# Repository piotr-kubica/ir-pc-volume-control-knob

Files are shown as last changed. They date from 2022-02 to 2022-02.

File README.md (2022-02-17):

# ir-pc-volume-control-knob
IR and PC volume control knob allows to control 
- prev/next/play/volume on your PC
- tuner/audio-in/on/off/volume of the Denon RCD-M39 amplituner using IR

The goal of this project was to create a volume control knob for multiple devices.

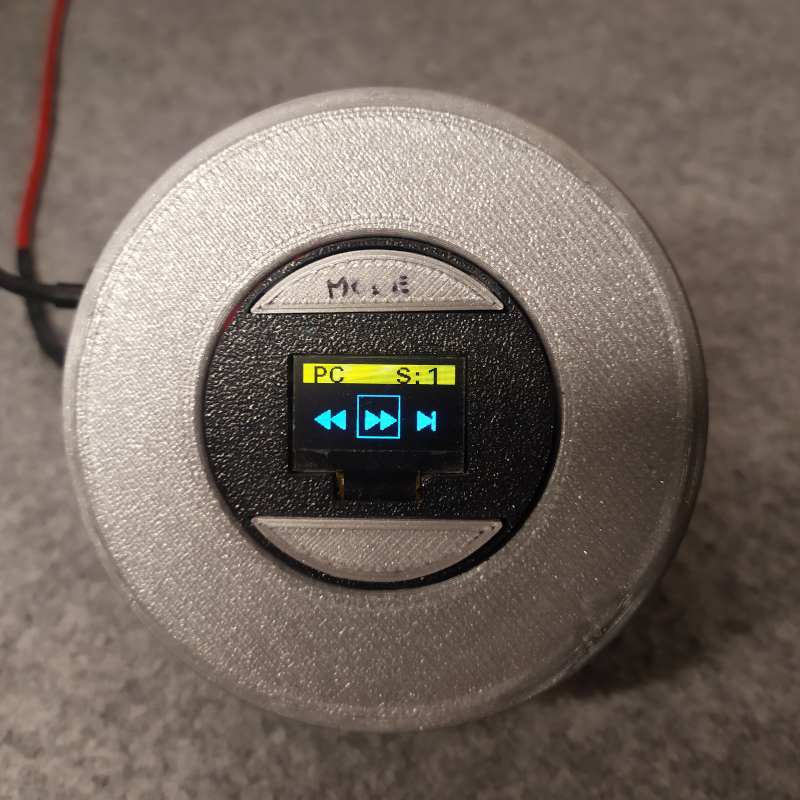
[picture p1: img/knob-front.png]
[](/img/knob-front.png)

## Hardaware
- SparkFun Pro Micro 5v/16Mhz 
- rotary encoder
- ssd1306 oled display (i2c version)
- IR led, transistor and resistor (used in the IR transmitter)
- 3D printed case (see stl and 3mf files)
- M3 bolts, 2x tactile buttons, JST connector and socket, wires, proto board, USB cable, rubber pad (so the knob does not slip on flat surface)

## Software 

I have used Arduino Studio to upload ir-pc-volume-control-knob.ino to the MCU.
I have also created a custom font using the png2bdf cli tool.

## How the control know works
Volume increase/decrease by turning the knob left/right.

Mute by clicking the mute button (it will mute the device with active mode).

Mode is changed by clicking the mode button.

Press once in clickable area to enter selection for mode.
Navigate by turning knob. Press angain to select.

Double click clickable area to change volume stepping ("S:1" or "S:2") for move volume per knob turn.

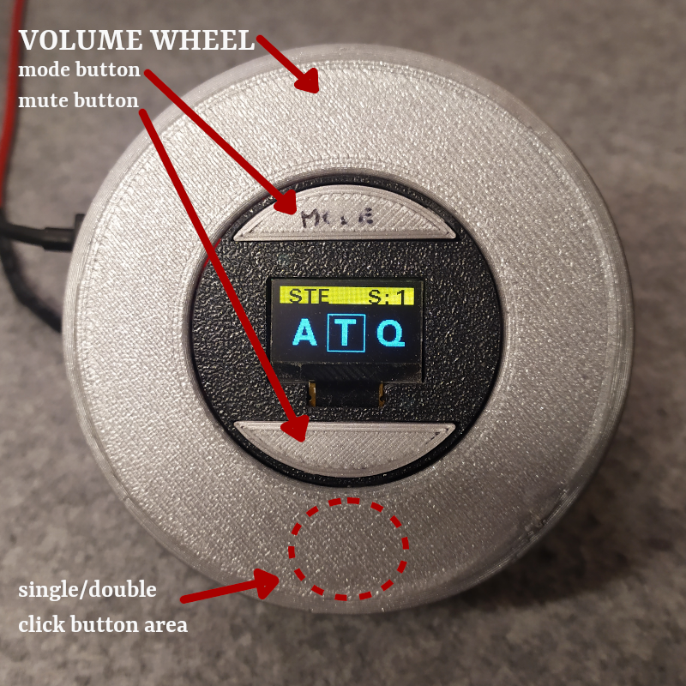
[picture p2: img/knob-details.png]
[](/img/knob-details.png)

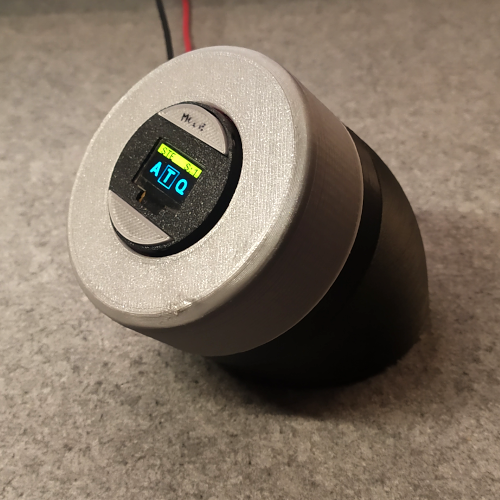
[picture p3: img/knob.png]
[](/img/knob.png )
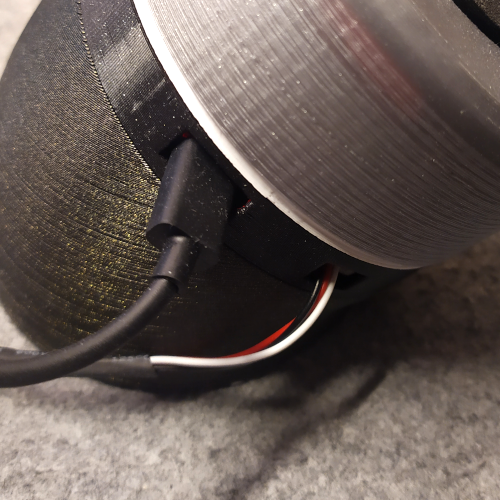
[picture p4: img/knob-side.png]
[](/img/knob-side.png)
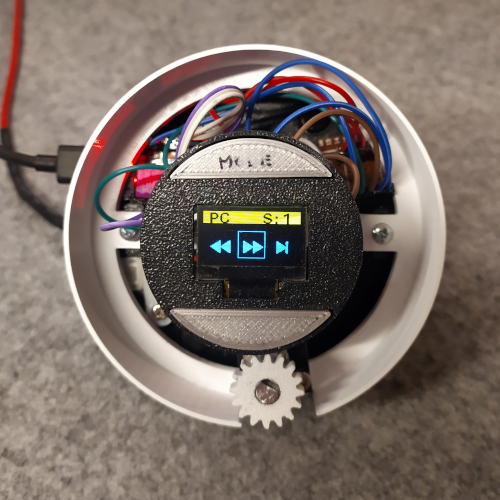
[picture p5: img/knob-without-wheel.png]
[](/img/knob-without-wheel.png)
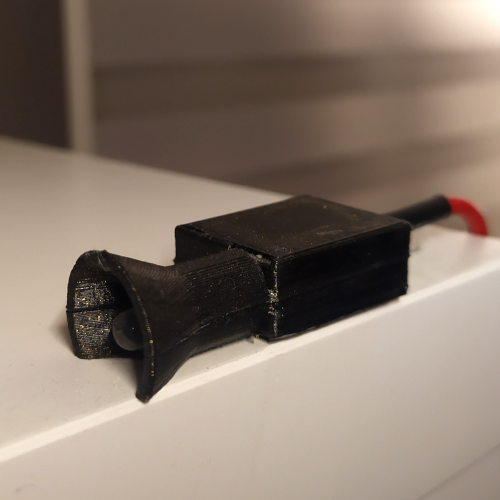
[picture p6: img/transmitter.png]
[](/img/transmitter.png)
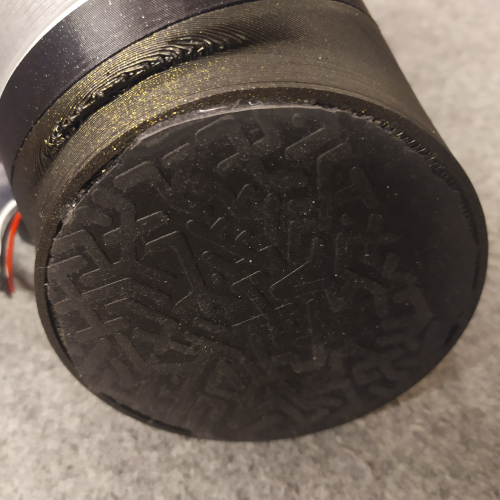
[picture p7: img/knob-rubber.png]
[](/img/knob-rubber.png)

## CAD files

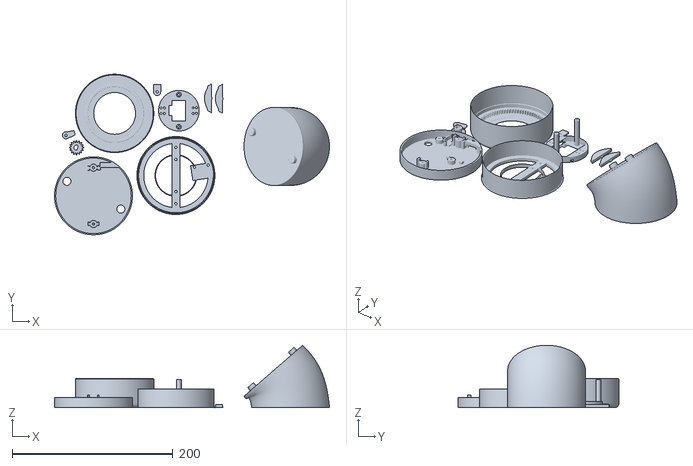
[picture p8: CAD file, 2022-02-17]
stl_3mf/ir-pc-remote-vol-knob.stl
342.1 x 199.8 x 77.6

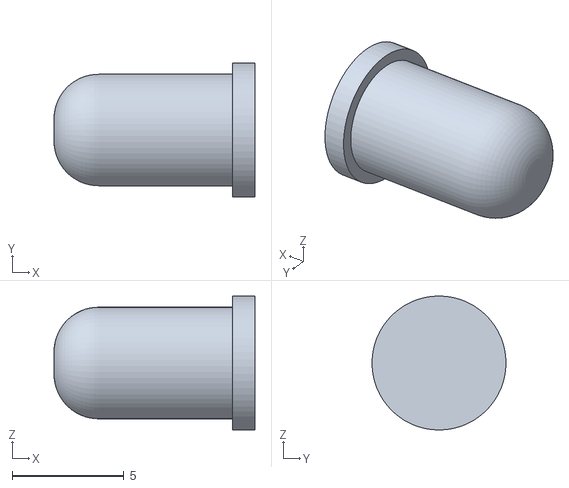
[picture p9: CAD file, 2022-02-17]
stl_3mf/ir-pilot-led.stl
9.00 x 5.99 x 6.00

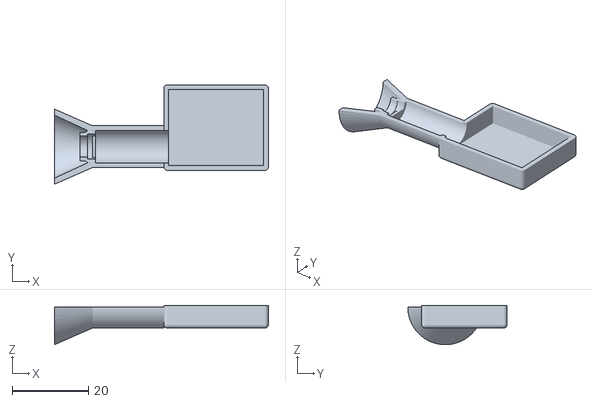
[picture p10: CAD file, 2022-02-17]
stl_3mf/ir-pilot-case.stl
56.2 x 26.1 x 10.3

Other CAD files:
stl_3mf/ir-pc-control-knob-final.3mf

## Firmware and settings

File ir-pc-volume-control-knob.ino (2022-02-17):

/* ProMicro PIN <-> WIRE COLOR MAPPING

3 white oled SCK
2 violet oled SDA

7 btn bonze
8 btn green

A2 violet enc CLK
A1 gray enc DT
A0 white enc SW

*/
#include <Arduino.h>
#include <U8g2lib.h>
#include <SPI.h>
#include <Wire.h>

#include <ClickEncoder.h>
#include <TimerOne.h>
#include <HID-Project.h>
#include <ClickButton.h>
#include <IRremote.h>

#define ENCODER_CLK A0
#define ENCODER_DT A1
#define ENCODER_SW A2
#undef  ENC_DOUBLECLICKTIME
#define ENC_DOUBLECLICKTIME  1500
#undef  ENC_HOLDTIME
#define ENC_HOLDTIME 2000 
#define STEPS_PER_NOTCH 4
ClickEncoder *rotEnc;
int16_t rotLast = 0;
int16_t rotValue = 0;
#define INVERT_KNOB_DIR 1

#define BTN_MODE 7
#define BTN_MUTE 8
ClickButton btn_mode(BTN_MODE, LOW);
ClickButton btn_mute(BTN_MUTE, LOW);

#define MODE_STEREO 0
#define MODE_PC 1
uint8_t mode = MODE_STEREO;
uint8_t mode_offset = 0;
uint8_t volume_step = 1;
String pc_header = String("PC       S: ");
String ste_header = String("STE      S: ");

IRsend irsend;
#define IR_KHZ 38
// no need to #define IR_SEND_PIN 5
// since it's default

#define OLED1306_SCK 3
#define OLED1306_SDA 2
U8G2_SSD1306_128X64_NONAME_1_SW_I2C u8g2(U8G2_R0, OLED1306_SCK, OLED1306_SDA);

#define FIELDS 3
#if INVERT_KNOB_DIR
    #define FIELD_DIFF_NEXT FIELDS-1
    #define FIELD_DIFF_PREV 1
#else
    #define FIELD_DIFF_NEXT 1
    #define FIELD_DIFF_PREV FIELDS-1
#endif

int selected = 1;
int active_choice = false;
unsigned long millis_since_choice = 0;
unsigned long active_choice_timeout_ms = 2000;

// mycust font
#include "mycust_font.h"
// Font list: https://github.com/olikraus/u8g2/wiki/fntlistall
//  https://github.com/olikraus/u8g2/wiki/fntgrpiconic
const int GLYPHS[][3] = { 
    // PC
    { 8, 58, 'C'},  // prev
    {48, 58, 'A'}, // next
    {88, 58, 'B'}, // play/pause
    // STEREO
    {12, 54, 'A'}, // audio in
    {52, 54, 'T'}, // tuner
    {92, 54, 'Q'}, // on / off
};
const int BOX_POS[][4] = { 
    {6, 24, 36, 36},
    {46, 24, 36, 36},
    {86, 24, 36, 36},
};

// size of each array is 99
#define IR_CODE_SIZE 99
const uint16_t IR_AU_IN[]  PROGMEM = {3300,1700, 350,500, 350,450, 350,1350, 350,450, 350,1350, 350,450, 350,1300, 350,500, 350,500, 350,1300, 350,500, 350,450, 350,1300, 350,1350, 350,450, 350,500, 350,500, 350,450, 350,500, 350,450, 350,1350, 350,450, 350,1350, 350,450, 350,500, 350,1300, 350,500, 350,450, 350,500, 350,500, 350,450, 350,1300, 350,500, 350,500, 350,450, 350,500, 350,500, 350,450, 350,1300, 350,500, 350,500, 350,1300, 350,500, 350,450, 350,1300, 350,500, 350,500, 350,1300, 350};
const uint16_t IR_TUNER[]  PROGMEM = {3300,1700, 350,450, 400,450, 350,1300, 350,500, 350,1300, 400,450, 350,1300, 350,450, 400,450, 400,1250, 350,500, 400,450, 350,1300, 350,1300, 400,450, 350,450, 400,450, 400,450, 350,450, 400,450, 350,1300, 400,450, 350,1300, 350,500, 350,450, 400,1250, 400,1300, 350,450, 400,1300, 350,1300, 350,1300, 400,450, 350,450, 400,450, 400,450, 350,450, 400,450, 350,450, 400,1300, 350,450, 400,450, 350,1300, 400,1250, 400,450, 400,450, 350,1300, 350,1300, 400,450, 350};
const uint16_t IR_PWR[]    PROGMEM = {3250,1750, 300,500, 350,500, 300,1350, 350,500, 300,1350, 350,500, 300,1350, 300,550, 300,550, 300,1350, 300,550, 250,550, 300,1400, 250,1350, 350,500, 300,500, 350,550, 250,550, 300,500, 350,550, 250,1350, 350,500, 300,1350, 300,550, 300,1350, 300,550, 300,500, 350,500, 300,1350, 300,1350, 350,500, 300,550, 300,500, 350,500, 300,500, 350,500, 300,550, 300,500, 350,1350, 300,500, 300,1350, 350,500, 300,550, 300,500, 350,500, 300,1350, 300,550, 350,450, 350};
const uint16_t IR_MUTE[]   PROGMEM = {3300,1700, 400,450, 350,450, 400,1250, 400,450, 400,1250, 400,450, 400,1250, 400,450, 350,450, 400,1300, 350,450, 400,450, 400,1250, 400,1250, 400,450, 400,450, 350,450, 400,450, 350,450, 400,450, 400,1250, 400,450, 400,1250, 400,450, 350,1300, 400,450, 350,450, 400,450, 400,450, 350,1300, 350,1300, 400,450, 350,450, 400,450, 400,450, 350,450, 400,450, 350,450, 400,1300, 350,450, 400,1300, 350,450, 400,450, 350,450, 400,1300, 350,1300, 400,1250, 400,450, 350};
const uint16_t IR_VOL_UP[] PROGMEM = {3300,1700, 350,450, 400,450, 400,1250, 400,450, 350,1300, 400,450, 350,1300, 400,450, 350,450, 400,1300, 350,450, 400,450, 350,1300, 400,1250, 400,450, 350,450, 400,450, 400,450, 350,450, 400,450, 400,1250, 400,450, 350,1300, 400,450, 350,1300, 400,450, 350,450, 400,450, 350,450, 400,450, 400,1250, 400,450, 350,500, 350,450, 400,450, 350,450, 400,450, 400,450, 350,1300, 350,500, 350,1300, 350,450, 400,450, 400,450, 350,1300, 350,500, 350,1300, 350,450, 400};
const uint16_t IR_VOL_DN[] PROGMEM = {3250,1700, 350,500, 350,500, 350,1300, 350,500, 350,1300, 350,450, 350,1350, 350,450, 350,500, 350,1300, 350,500, 350,450, 350,1350, 350,1300, 350,500, 300,500, 350,500, 350,450, 350,500, 350,500, 350,1300, 350,500, 300,1350, 350,450, 350,1350, 350,450, 350,500, 350,500, 300,1350, 350,450, 350,1350, 350,450, 350,500, 350,500, 300,500, 350,500, 350,450, 350,500, 350,1300, 350,500, 350,1300, 350,500, 350,450, 350,500, 350,500, 350,450, 350,1350, 300,500, 350};

const uint16_t * const ir_codes[] = {IR_AU_IN, IR_TUNER, IR_PWR, IR_MUTE, IR_VOL_UP, IR_VOL_DN};

#define AU_IN 0
#define TUNER 1
#define PWR 2
#define MUTE 3
#define VOL_UP 4
#define VOL_DN 5

// On the Zero and others we switch explicitly to SerialUSB
#if defined(ARDUINO_ARCH_SAMD)
#define Serial SerialUSB
#endif

void refresh_active_choice_timeout() {
    millis_since_choice = millis();
}

void clear_active_choice() {
    millis_since_choice = millis() + active_choice_timeout_ms;
}

void ir_send(int ir_id) {
    unsigned int code[99];
    for (byte i = 0; i < IR_CODE_SIZE; i++) {
        code[i] = pgm_read_word_near(ir_codes[ir_id] + i);
        Serial.print(String(code[i]) + " ");
    }
    Serial.println();
    irsend.sendRaw(code, sizeof(code) / sizeof(code[0]), IR_KHZ);
}

void vol_up() {
    if (mode == MODE_PC) {
        int step_copy = volume_step;
        while(step_copy--) {
            Consumer.write(MEDIA_VOLUME_UP);
        }
    } else { // STEREO
        int step_copy = volume_step;
        while(step_copy--) {
            ir_send(VOL_UP);
            delay(200);
        }
    }
}

void vol_dn() {
    if (mode == MODE_PC) {
        int step_copy = volume_step;
        while(step_copy--) {
            Consumer.write(MEDIA_VOLUME_DOWN);
        }
    } else { // STEREO
        int step_copy = volume_step;
        while(step_copy--) {
            ir_send(VOL_DN);
            delay(200);
        }
    }
}

void handleRotEncoderTurn() {
    int16_t encValue = rotEnc->getValue();
    rotValue += encValue;

    if (rotValue > rotLast) {
        if(!active_choice) {
            vol_dn();
        } else {
            selected = (selected + FIELD_DIFF_NEXT)%FIELDS;    
        }
    } else if(rotValue < rotLast) {
        if(!active_choice) {
            vol_up();
        } else {
            selected = (selected + FIELD_DIFF_PREV)%FIELDS;
        }
    }
    if (rotLast != rotValue) {
        refresh_active_choice_timeout();
    }
    rotLast = rotValue;
}

void handleRotEncoderClick(){
    ClickEncoder::Button btn = rotEnc->getButton();
    
    if (btn == ClickEncoder::Clicked) {
        Serial.println("Rot encoder Click");
        if(!active_choice) {
            active_choice = true;
            refresh_active_choice_timeout();
        } else {
            if(mode == MODE_PC){
                if (selected==0) {
                    Consumer.write(MEDIA_PREVIOUS);
                } else if (selected==1) {
                    Consumer.write(MEDIA_NEXT);
                } else if (selected==2) {
                    Consumer.write(MEDIA_PLAY_PAUSE);
                }
            } else {
                if (selected==0) {
                    ir_send(AU_IN);
                } else if (selected==1) {
                    ir_send(TUNER);
                } else if (selected==2) {
                    ir_send(PWR);
                }
            }
            clear_active_choice();
        }
    } else if(btn == ClickEncoder::DoubleClicked) {
        Serial.println("Rot encoder 2-Click");
        volume_step = volume_step%2 + 1;
    }
}

void timerIsr() {
  rotEnc->service();
}

void detect_buttons() {
    btn_mode.Update();
    if (btn_mode.changed) {
        Serial.println("btn_mode");
        mode = (mode+1) % 2;
        
        refresh_active_choice_timeout();
    }
    
    btn_mute.Update();
    if (btn_mute.changed) {
        // Serial.println("btn_mute");
        if (mode == MODE_PC) {
            // Serial.println("[PC] mute");
            Consumer.write(MEDIA_VOLUME_MUTE);
        } else {
            // Serial.println("[STEREO] mute");
            ir_send(MUTE);
        }
        refresh_active_choice_timeout();
    }
}

void display_oled() {
    u8g2.firstPage();  
    do {
      u8g2.setFontMode(1);  /* activate transparent font mode */
      u8g2.setDrawColor(1); /* color 1 for the box */
      u8g2.drawBox(0, 0, 128, 16);
      u8g2.setDrawColor(0);
      u8g2.setFont(u8g2_font_fub14_tr);
      
      if (mode == MODE_PC) {
        u8g2.drawStr(8, 16, (pc_header+volume_step).c_str());
        u8g2.setFont(mycust_font);
        mode_offset = 0;
      } else {
        u8g2.drawStr(8, 16, (ste_header+volume_step).c_str());
        u8g2.setFont(u8g2_font_fub25_tr);
        mode_offset = 3;
      }

      for(int i=0; i<FIELDS; i++) {
        u8g2.setDrawColor(1);
        if(i==selected) {
            if(active_choice) {
                u8g2.drawBox(BOX_POS[i][0], BOX_POS[i][1], BOX_POS[i][2], BOX_POS[i][3]);
                u8g2.setDrawColor(0);
            } else {
                u8g2.drawFrame(BOX_POS[i][0], BOX_POS[i][1], BOX_POS[i][2], BOX_POS[i][3]);
            }
            u8g2.drawGlyph(GLYPHS[i+mode_offset][0], GLYPHS[i+mode_offset][1], GLYPHS[i+mode_offset][2]);    
            
        } else {
            u8g2.drawGlyph(GLYPHS[i+mode_offset][0], GLYPHS[i+mode_offset][1], GLYPHS[i+mode_offset][2]);
        }
      }  
      
      detect_buttons();
    } while( u8g2.nextPage() );
}

void setup(void) {
    Serial.begin(9600);

    #if defined(SERIAL_USB) || defined(SERIAL_PORT_USBVIRTUAL)
    delay(2000); // To be able to connect Serial monitor after reset and before first printout
    #endif
    
    u8g2.begin();
    
    // Initializes the rotary encoder with the mentioned pins
    rotEnc = new ClickEncoder(ENCODER_CLK, ENCODER_DT, ENCODER_SW, STEPS_PER_NOTCH); 
    Timer1.initialize(500); // Initializes the timer, which the rotary encoder uses to detect rotation
    Timer1.attachInterrupt(timerIsr); 

    btn_mode.multiclickTime = 150; // default is 250
    btn_mute.multiclickTime = 150; // default is 250

    pinMode(BTN_MODE, INPUT_PULLUP);
    pinMode(BTN_MUTE, INPUT_PULLUP);
}

void loop(void) {
    handleRotEncoderTurn();
    handleRotEncoderClick();

    // detect_buttons() is inside display_oled to reduce lag
    if (millis() - millis_since_choice > active_choice_timeout_ms) {
        active_choice = false;
    }
    display_oled();
    delay(5);
}
